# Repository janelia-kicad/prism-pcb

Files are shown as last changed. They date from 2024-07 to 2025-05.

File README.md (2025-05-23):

- [Repository Info](#org828f207)
- [Images](#orgb7f0c41)
- [Schematic](#org1bb097a)
- [PCB](#orgb5dbdc9)
- [Bill of Materials](#orgcb18792)
- [Development](#org51ea665)

    <!-- This file is generated automatically from metadata -->
    <!-- File edits may be overwritten! -->

# Repository Info

-   Project Name: prism-pcb
-   Synopsis: PCB for each prism in the Voigts Lab honeycomb maze.
-   Documentation Version: 2.1.0
-   Pcb Version: 2.1
-   Enclosure Version: 1.0
-   Supplemental BOM Version: 2.1.0
-   Release Date: 2025-05-23
-   Creation Date: 2024-06-27
-   Kicad Version: 9.0
-   License: BSD-3-Clause
-   URL: <https://github.com/janelia-kicad/prism-pcb>
-   Author: Peter Polidoro
-   Email: peter@polidoro.io
-   Copyright: 2025 Howard Hughes Medical Institute
-   References:
    -   [cluster-pcb](https://github.com/janelia-kicad/cluster-pcb)
    -   [TMC5130](https://www.analog.com/en/products/tmc5130.html)

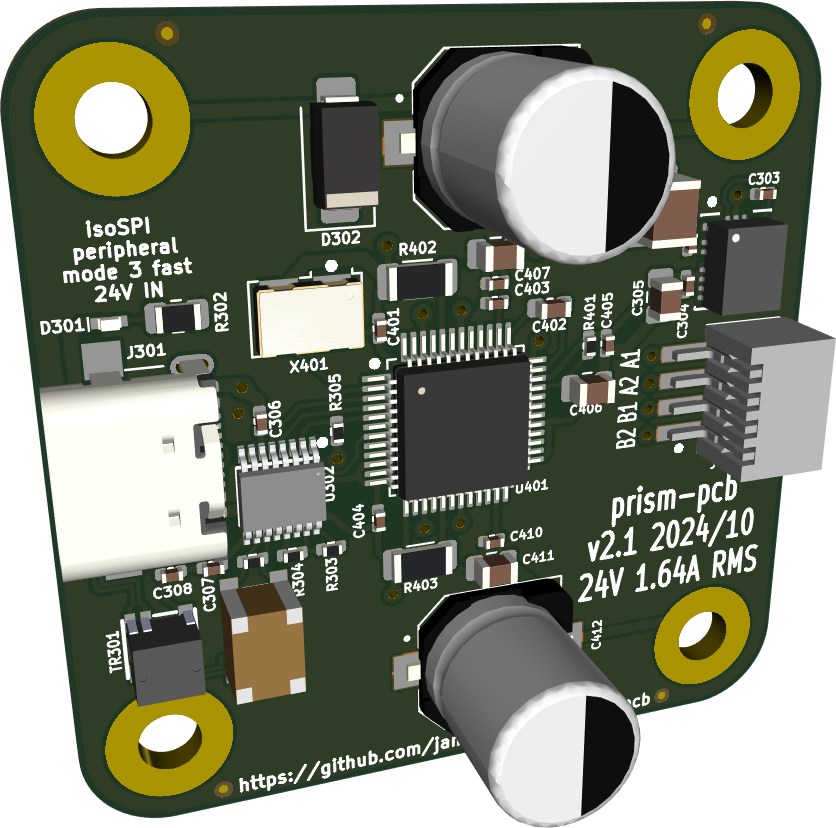
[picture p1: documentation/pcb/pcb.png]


# Images

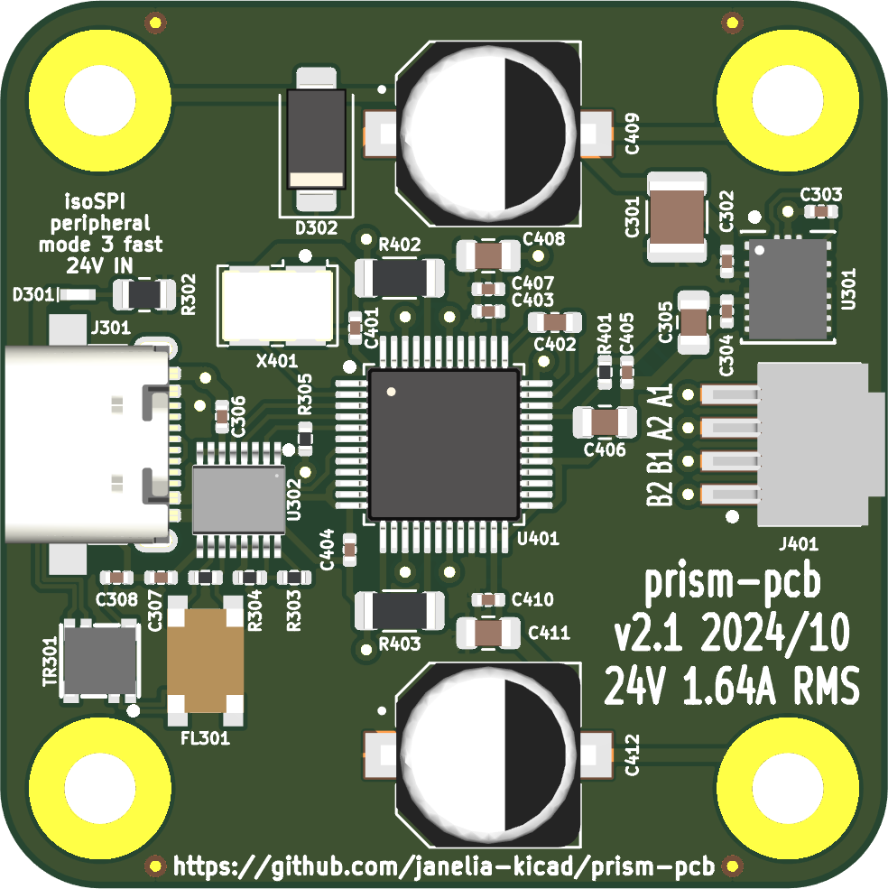
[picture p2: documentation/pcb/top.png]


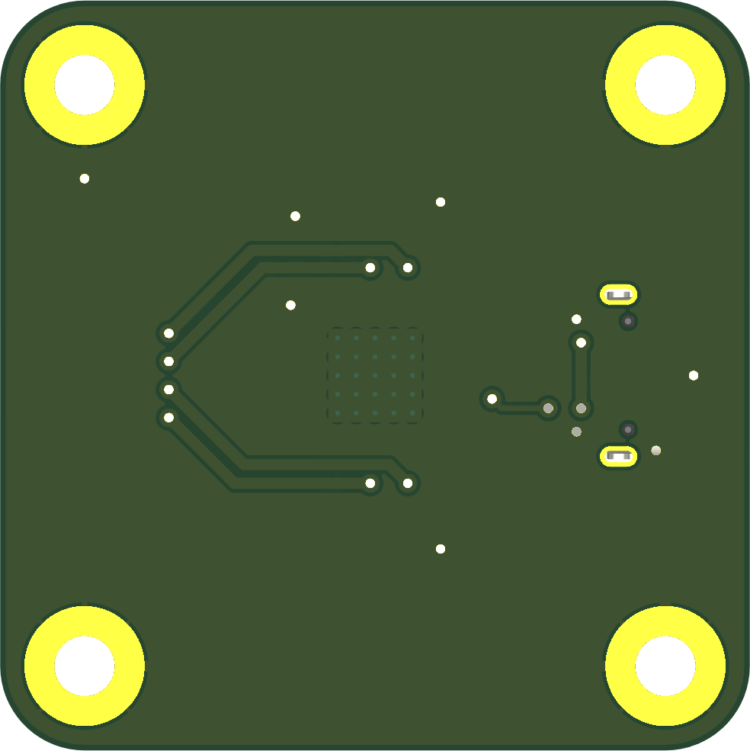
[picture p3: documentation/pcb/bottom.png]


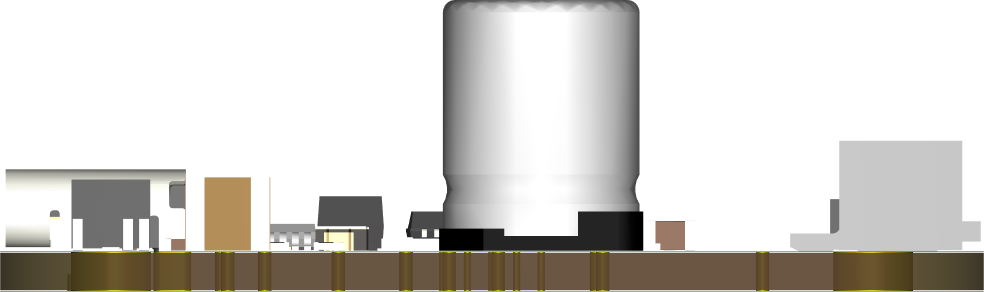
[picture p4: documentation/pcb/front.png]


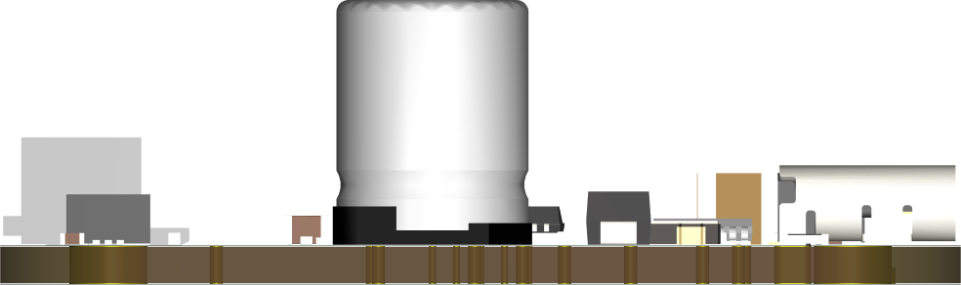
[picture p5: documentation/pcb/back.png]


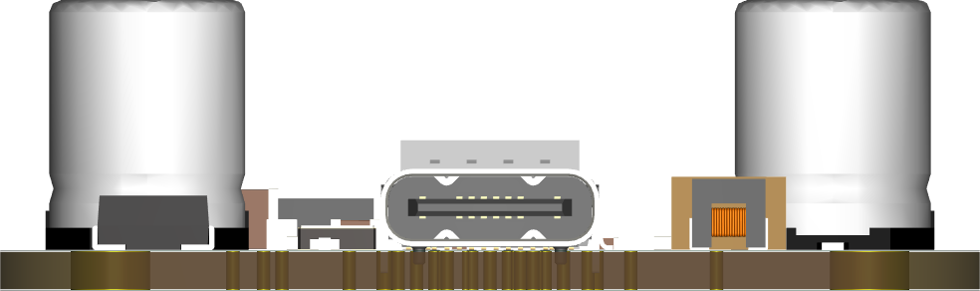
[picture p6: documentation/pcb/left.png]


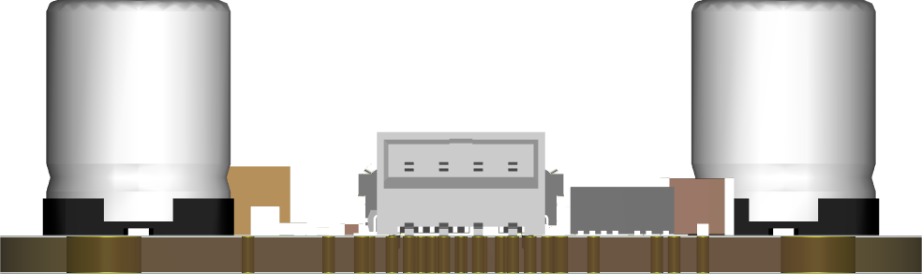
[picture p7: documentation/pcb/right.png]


# Schematic

[./documentation/schematic/prism-pcb.pdf](./documentation/schematic/prism-pcb.pdf)









# PCB











# Bill of Materials

## Board

| Item | Synopsis | Manufacturer Part Number | Manufacturer | Quantity | Reference(s) | Package |
|---- |--- |--- |--- |--- |--- |--- |
| 1 | 50V 3.3uF | FS32X335K500EGG | PSA(Prosperity Dielectrics) | 1 | C301 | 1210 |
| 2 | CAP CER 0.1UF 100V X5R | GRM155R62A104KE14D | Murata Electronics | 8 | C302 C306 C307 C401 C403 C404 C407 C410 | 0402 |
| 3 | CAP CER 1UF 25V X5R | GRT155R61E105KE01D | Murata Electronics | 2 | C303 C304 | 0402 |
| 4 | CAP CER 47UF 10V X5R | CGA0805X5R476M100MT | HRE | 2 | C305 C406 | 0805 |
| 5 | CAP CER 27pF 50V 5% | 0402CG270J500NT | FH (Guangdong Fenghua Advanced Tech) | 1 | C308 | 0402 |
| 6 | CAP CER 0.022UF 100V X7R | GCM188R72A223KA37D | Murata Electronics | 1 | C402 | 0603 |
| 7 | CAP CER 0.47UF 35V X5R | GRT155R6YA474KE01D | Murata Electronics | 1 | C405 | 0402 |
| 8 | CAP CER 2.2UF 100V X7T 0805 | GRM21BD72A225KE01L | Murata Electronics | 2 | C408 C411 | 0805 |
| 9 | CAP ALUM 100UF 20% 50V SMD | EEEHAH101UAP | Panasonic Electronic Components | 2 | C409 C412 | SMD D8xL10.2mm |
| 10 | LED RED CLEAR CHIP SMD | APHHS1005SURCK | Kingbright | 1 | D301 | 0402 |
| 11 | DIODE GEN PURP 200V 2A | ES2D | GOODWORK | 1 | D302 | SMA(DO-214AC) |
| 12 | CMC 22UH 200MA 2LN 1.2KOHM SMD | ACT45B-220-2P-TL003 | TDK | 1 | FL301 | 1812 |
| 13 | USB Type-C 2.0 16P 5A | GT-USB-7047C | G-Switch | 1 | J301 | SMD |
| 14 | CONN HEADER SMD R/A 4POS 1.5MM | 0874380443 | Molex | 1 | J401 | SMD |
| 15 | RES SMD 100 OHM 1% 62.5mW | 0402WGF1000TCE | UNI-ROYAL(Uniroyal Elec) | 1 | R301 | 0402 |
| 16 | RA73F 2A 2K32 0.1% 5K RL | RA73F2A2K32BTD | TE Connectivity Passive Product | 1 | R302 | 0805 |
| 17 | RES SMD 1.4K OHM 1% 62.5mW | RC0402FR-071K4L | YAGEO | 1 | R303 | 0402 |
| 18 | RES SMD 604 OHM 1% 100mW | ERJ2RKF6040X | PANASONIC | 1 | R304 | 0402 |
| 19 | RES SMD 1.8K OHM 5% 100mW | ERJ2GEJ182X | PANASONIC | 1 | R305 | 0402 |
| 20 | RES SMD 10 OHM 1% 62.5mW | RC0402FR-0710RL | YAGEO | 1 | R401 | 0402 |
| 21 | 0.12 750mW Current Sense Resistor | KRL1632E-M-R120-F-T5 | SUSUMU | 2 | R402 R403 | 1206 |
| 22 | Pulse Transformer 120uH 1CT:1CT | FB020G00 | Dongguan Mentech Optical & Magnetic  | 1 | TR301 | SMD-6P 3.5x3.2mm |
| 23 | DC-DC 5V 600mA Output 3-65V Input | TPSM365R6V5RDNR | Texas Instruments | 1 | U301 | QFN-11(3.5x4.5)  |
| 24 | SPI Isolator | LTC6820HMS#3ZZTRPBF | Analog Devices | 1 | U302 | MSOP-16 |
| 25 | IC MTR DRV BIPOLAR 5.5-46V | TMC5130A-TA | Analog Devices Inc./Maxim Integrated | 1 | U401 | TQFP-48-EP(7x7)  |
| 26 | XTAL OSC XO 16MHZ 5V SMD | S5D16.000000A20F30T | Shenzhen SCTF Elec | 1 | X401 | SMD5032-4P |

## Supplemental

| Item | Synopsis | Manufacturer Part Number | Manufacturer | Quantity | Cost  | Total |
|---- |--- |--- |--- |--- |----- |----- |
| 1 | USB 2.0 C Male to C Male 150mm | DH-20UE0062-NH | Cvilux USA | 1 | 4.75  | 4.75  |
| 2 | USB 2.0 C Male to C Male 1m | DH-20UE0063-NH | Cvilux USA | 1 | 5.74  | 5.74  |
| 3 | M3 Hex Standoff Male Female 10x5mm | 971100354 | Würth Elektronik | 4 | 0.63  | 2.52  |
| 4 | M3 Machine Screw 6mm | RM3X6MM 2701 | APM Hexseal | 4 | 0.58  | 2.32  |
| 5 | Supplemental BOM Version: 2.1.0 | | | | Total | 15.33 |

# Development

## Install Guix

[Install Guix](https://guix.gnu.org/manual/en/html_node/Binary-Installation.html)

## Generate Output from KiCad

### Remove previous versions

```sh
rm -rf ./documentation/3dmodels/* && rm -rf ./documentation/bom/* && rm -rf ./documentation/fabrication/* && rm -rf ./documentation/pcb/* && rm -rf ./documentation/schematic/*pcb
```

### Images

1.  3D Viewer

    Output directory: ../documentation/pcb
    
    -   pcb.png
    -   top.png
    -   bottom.png
    -   front.png
    -   back.png
    -   left.png
    -   right.png

2.  Trim

        make trimmed-images

3.  Schematic PDF

    File -> Plot
    
    Output directory: ../documentation/schematic
    
    Plot All Pages
    
    -   Output format PDF
    -   Page Size = Schematic size
    -   Plot drawing sheet
    -   Output mode = Color
    -   Color theme = KiCad Default
    -   Default line width = 0.006 in

4.  Schematic SVG

    File -> Plot
    
    Output directory: ../documentation/schematic
    
    Plot All Pages
    
    -   Output format SVG
    -   Page Size = Schematic size
    -   Plot drawing sheet
    -   Output mode = Color
    -   Color theme = Solarized Light
    -   Default line width = 0.012 in

5.  PCB SVG

    Add Edge.Cuts, holes, and dimensions to User.Drawings
    
    File -> Plot
    
    Output directory: ../documentation/pcb
    
    -   Plot format SVG
    -   Include Layers
        -   User.Drawings
        -   F.Silkscreen
        -   B.Silkscreen
        -   F.Fab
        -   B.Fab
    -   Plot on All Layers
        -   Edge.Cuts
    -   Plot footprint values
    -   Plot reference designators
    -   SVG Options
        -   Precision = 4
        -   Output mode = color
    
        make cropped-svg

### Fabrication Files

1.  Gerbers

    File -> Fabrication Outputs -> Gerbers (.gbr)
    
    Output directory: ../documentation/fabrication/gerbers
    
    Include Layers:
    
    -   F.Cu
    -   F.Paste
    -   F.Silks
    -   F.Mask
    -   F.Fab
    -   B.Cu
    -   B.Paste
    -   B.Silks
    -   B.Mask
    -   B.Fab
    -   Edge.Cuts - (contain the board outline/cutouts.)
    -   In1.Cu, In2.Cu … - (needed for 4/6 layer designs.)
    
    Options:
    
    -   Select Plot reference designators, otherwise designators will not appear on silkscreen layers.
    -   Select Check zone fills before plotting
    -   Select Use Protel filename extensions, this is recommended as JLCPCB prefers Protel filename extensions.
    -   Select Subtract soldermask from silkscreen, this ensures no silkscreen on pads.
    -   Coordinate format 4.6 unit mm

2.  Drill and Map Files

    Output directory: ../documentation/fabrication/gerbers
    
    Options:
    
    -   Excellon drill file format
    -   Check Use alternate drill mode for "Oval Holes Drill Mode".
    -   Check Absolute for "Drill Origin".
    -   Check Millimeters for "Drill Units".
    -   Check Decimal format for "Zeros Format".
    -   Gerber X2 map file format
    
    Zip gerber files
    
        zip ./documentation/fabrication/gerbers.zip ./documentation/fabrication/gerbers/*

3.  BOM

    Generate BOM from schematic editor using blank command line to create bom xml file.

4.  POS

    File -> Fabrication Outputs -> Component Placement (.pos)
    
    Output directory: ../documentation/fabrication/
    
    Settings:
    
    -   Format = CSV
    -   Units = Millimeters
    -   Files = Single file for board
    -   Do not use drill/place file origin
    
    Modify pos files:
    
    -   Ref -> Designator
    -   PosX -> Mid X
    -   PosY -> Mid Y
    -   Rot -> Rotation
    -   Side -> Layer

5.  Step

    File -> Export -> Step
    
    Output directory: ../documentation/3dmodels/pcb.step
    
    -   Drill/place file origin
    -   Overwrite old file
    -   Standard Board outline chaining tolerance

## Edit metadata.org

    make metadata-edits

## Tangle metadata.org

    make metadata

## Edit project

    make kicad-edits
    exit

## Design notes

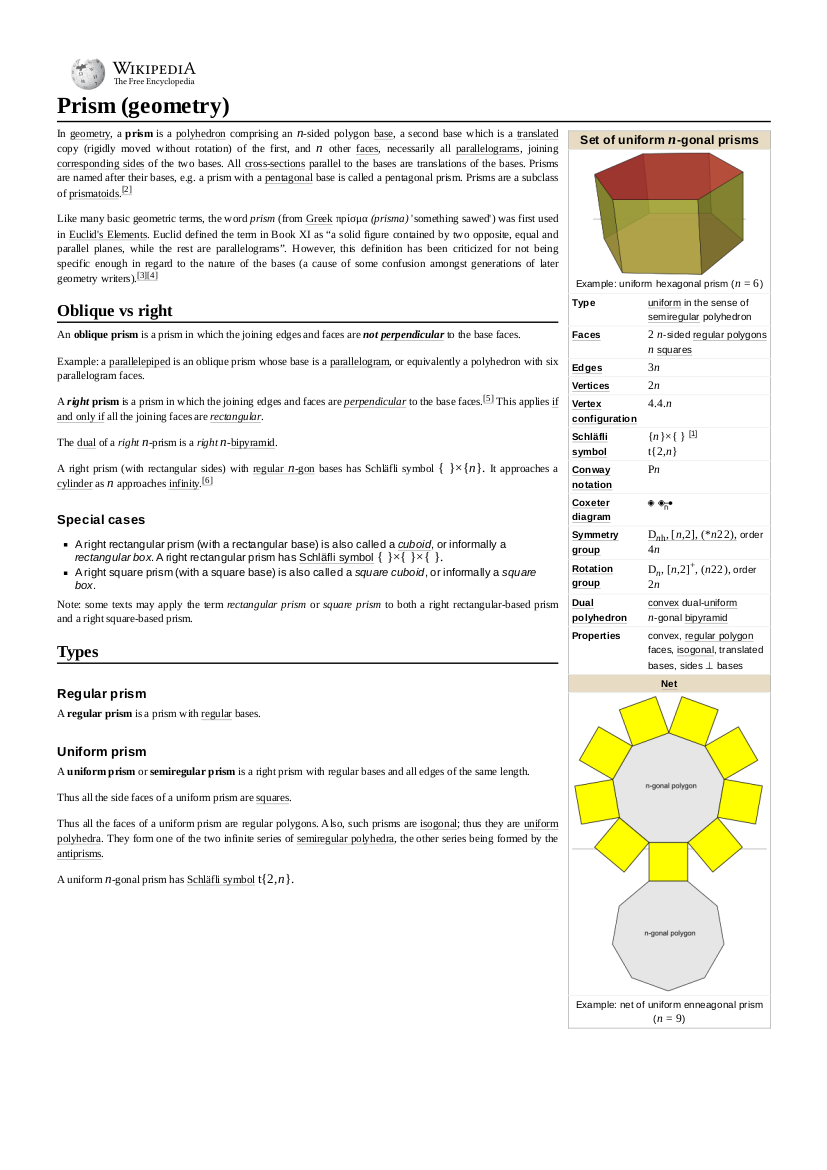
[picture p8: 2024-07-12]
documentation/images/prism.png

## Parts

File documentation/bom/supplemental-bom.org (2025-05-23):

#+OPTIONS: toc:nil title:nil num:nil ^:nil
#+LATEX_HEADER: \usepackage{adjustbox}
#+LATEX_HEADER: \usepackage[margin=2cm]{geometry}
* Supplemental BOM
- Project Name: prism-pcb
- Synopsis: PCB for each prism in the Voigts Lab honeycomb maze.
- Release Date: 2025-05-23
- URL: https://github.com/janelia-kicad/prism-pcb
- Author: Peter Polidoro
- Email: peter@polidoro.io
#+BEGIN_TABLE
#+LATEX: \adjustbox{max width=\linewidth}{
#+ATTR_LATEX: :center nil
| Item | Synopsis                                               | Manufacturer Part Number | Manufacturer     | Quantity |  Cost | Total |
|------+--------------------------------------------------------+--------------------------+------------------+----------+-------+-------|
|    1 | USB 2.0 C Male to C Male 150mm                         | DH-20UE0062-NH           | Cvilux USA       |        1 |  4.75 |  4.75 |
|    2 | USB 2.0 C Male to C Male 1m                            | DH-20UE0063-NH           | Cvilux USA       |        1 |  5.74 |  5.74 |
|    3 | M3 Hex Standoff Male Female 10x5mm                     | 971100354                | Würth Elektronik |        4 |  0.63 |  2.52 |
|    4 | M3 Machine Screw 6mm                                   | RM3X6MM 2701             | APM Hexseal      |        4 |  0.58 |  2.32 |
|------+--------------------------------------------------------+--------------------------+------------------+----------+-------+-------|
|    5 | Supplemental BOM Version: 2.1.0 |                          |                  |          | Total | 15.33 |
#+TBLFM: $1=@#-1::$7=$5*$6;%0.2f::@>$7=vsum(@2..@-1);%0.2f
#+LATEX: }
#+END_TABLE

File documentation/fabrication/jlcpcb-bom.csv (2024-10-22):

Comment | Designator | Footprint | LCSC
50V 3.3uF | C301 | 1210 | C1021610
CAP CER 0.1UF 100V X5R | C302 C306 C307 C401 C403 C404 C407 C410 | 0402 | C162178
CAP CER 1UF 25V X5R | C303 C304 | 0402 | C711085
CAP CER 47UF 10V X5R | C305 C406 | 0805 | C6119904
CAP CER 27pF 50V 5% | C308 | 0402 | C1557
CAP CER 0.022UF 100V X7R | C402 | 0603 | C161234
CAP CER 0.47UF 35V X5R | C405 | 0402 | C711580
CAP CER 2.2UF 100V X7T 0805 | C408 C411 | 0805 | C2981733
CAP ALUM 100UF 20% 50V SMD | C409 C412 | SMD D8xL10.2mm | C336425
LED RED CLEAR CHIP SMD | D301 | 0402 | C2852592
DIODE GEN PURP 200V 2A | D302 | SMA(DO-214AC) | C2922175
CMC 22UH 200MA 2LN 1.2KOHM SMD | FL301 | 1812 | C88055
USB Type-C 2.0 16P 5A | J301 | SMD | C963218
CONN HEADER SMD R/A 4POS 1.5MM | J401 | SMD | C564208
RES SMD 100 OHM 1% 62.5mW | R301 | 0402 | C25076
RA73F 2A 2K32 0.1% 5K RL | R302 | 0805 | C3961061
RES SMD 1.4K OHM 1% 62.5mW | R303 | 0402 | C375491
RES SMD 604 OHM 1% 100mW | R304 | 0402 | C2076855
RES SMD 1.8K OHM 5% 100mW | R305 | 0402 | C409855
RES SMD 10 OHM 1% 62.5mW | R401 | 0402 | C138066
0.12 750mW Current Sense Resistor | R402 R403 | 1206 | C2076122
Pulse Transformer 120uH 1CT:1CT | TR301 | SMD-6P 3.5x3.2mm | C19673866
DC-DC 5V 600mA Output 3-65V Input | U301 | QFN-11(3.5x4.5) | C19078014
SPI Isolator | U302 | MSOP-16 | C514444
IC MTR DRV BIPOLAR 5.5-46V | U401 | TQFP-48-EP(7x7) | C188832
XTAL OSC XO 16MHZ 5V SMD | X401 | SMD5032-4P | C387234

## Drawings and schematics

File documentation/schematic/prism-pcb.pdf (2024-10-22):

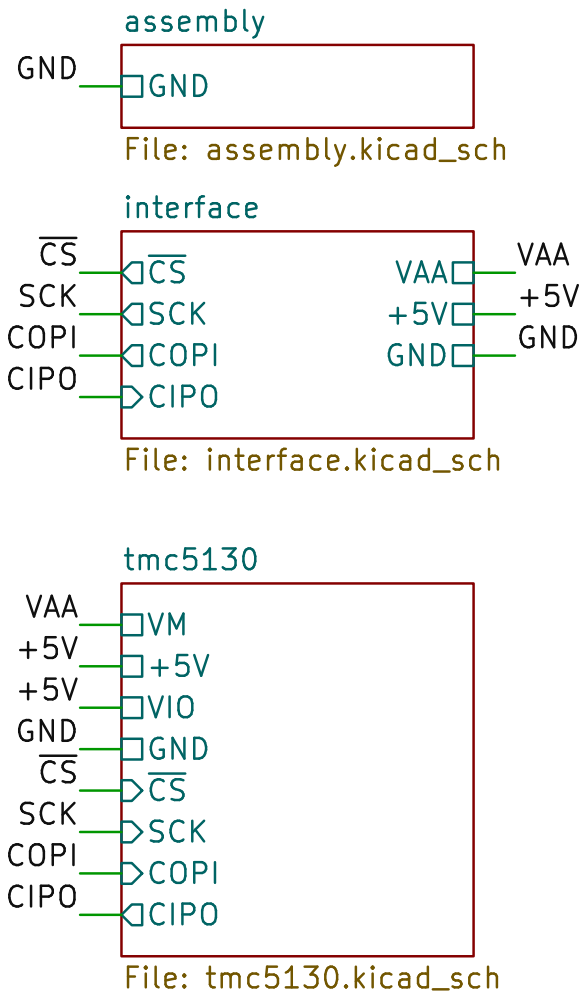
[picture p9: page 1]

interface File: interface.kicad_sch GND

SCK COPI ~{CS} CIPO

Id: 1/4 Title: prism-pcb

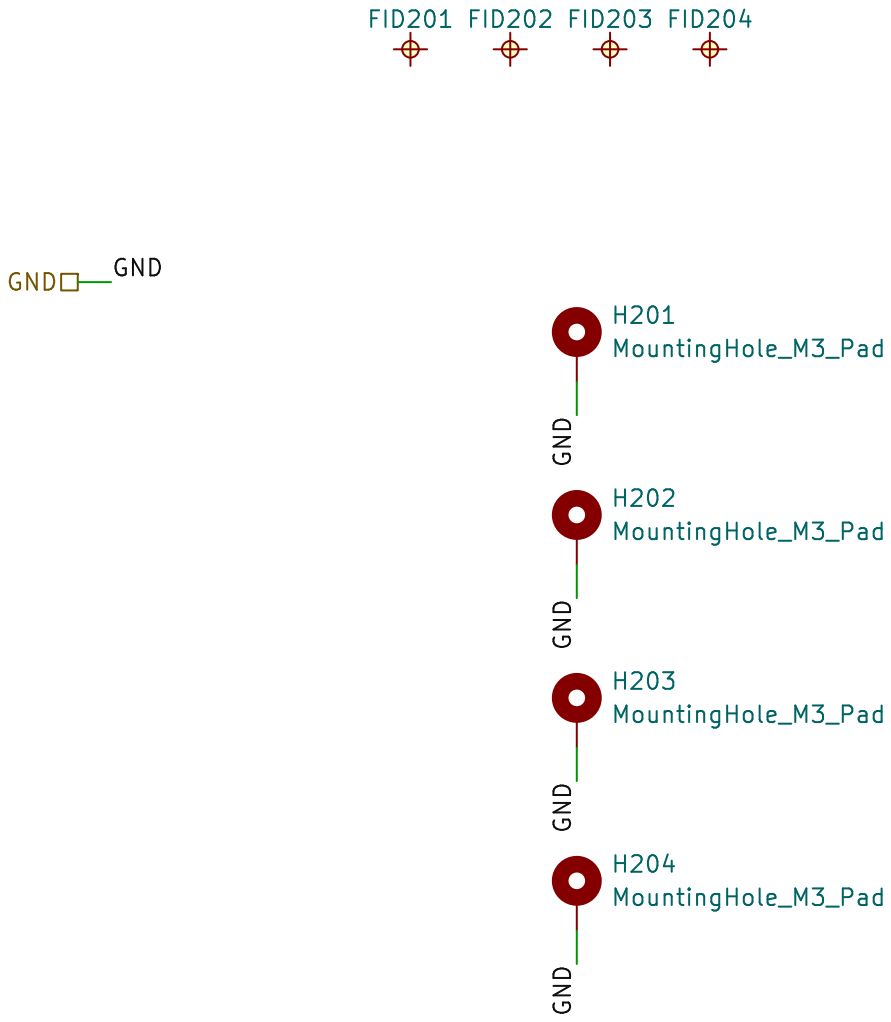
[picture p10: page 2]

Id: 2/4 Title: prism-pcb

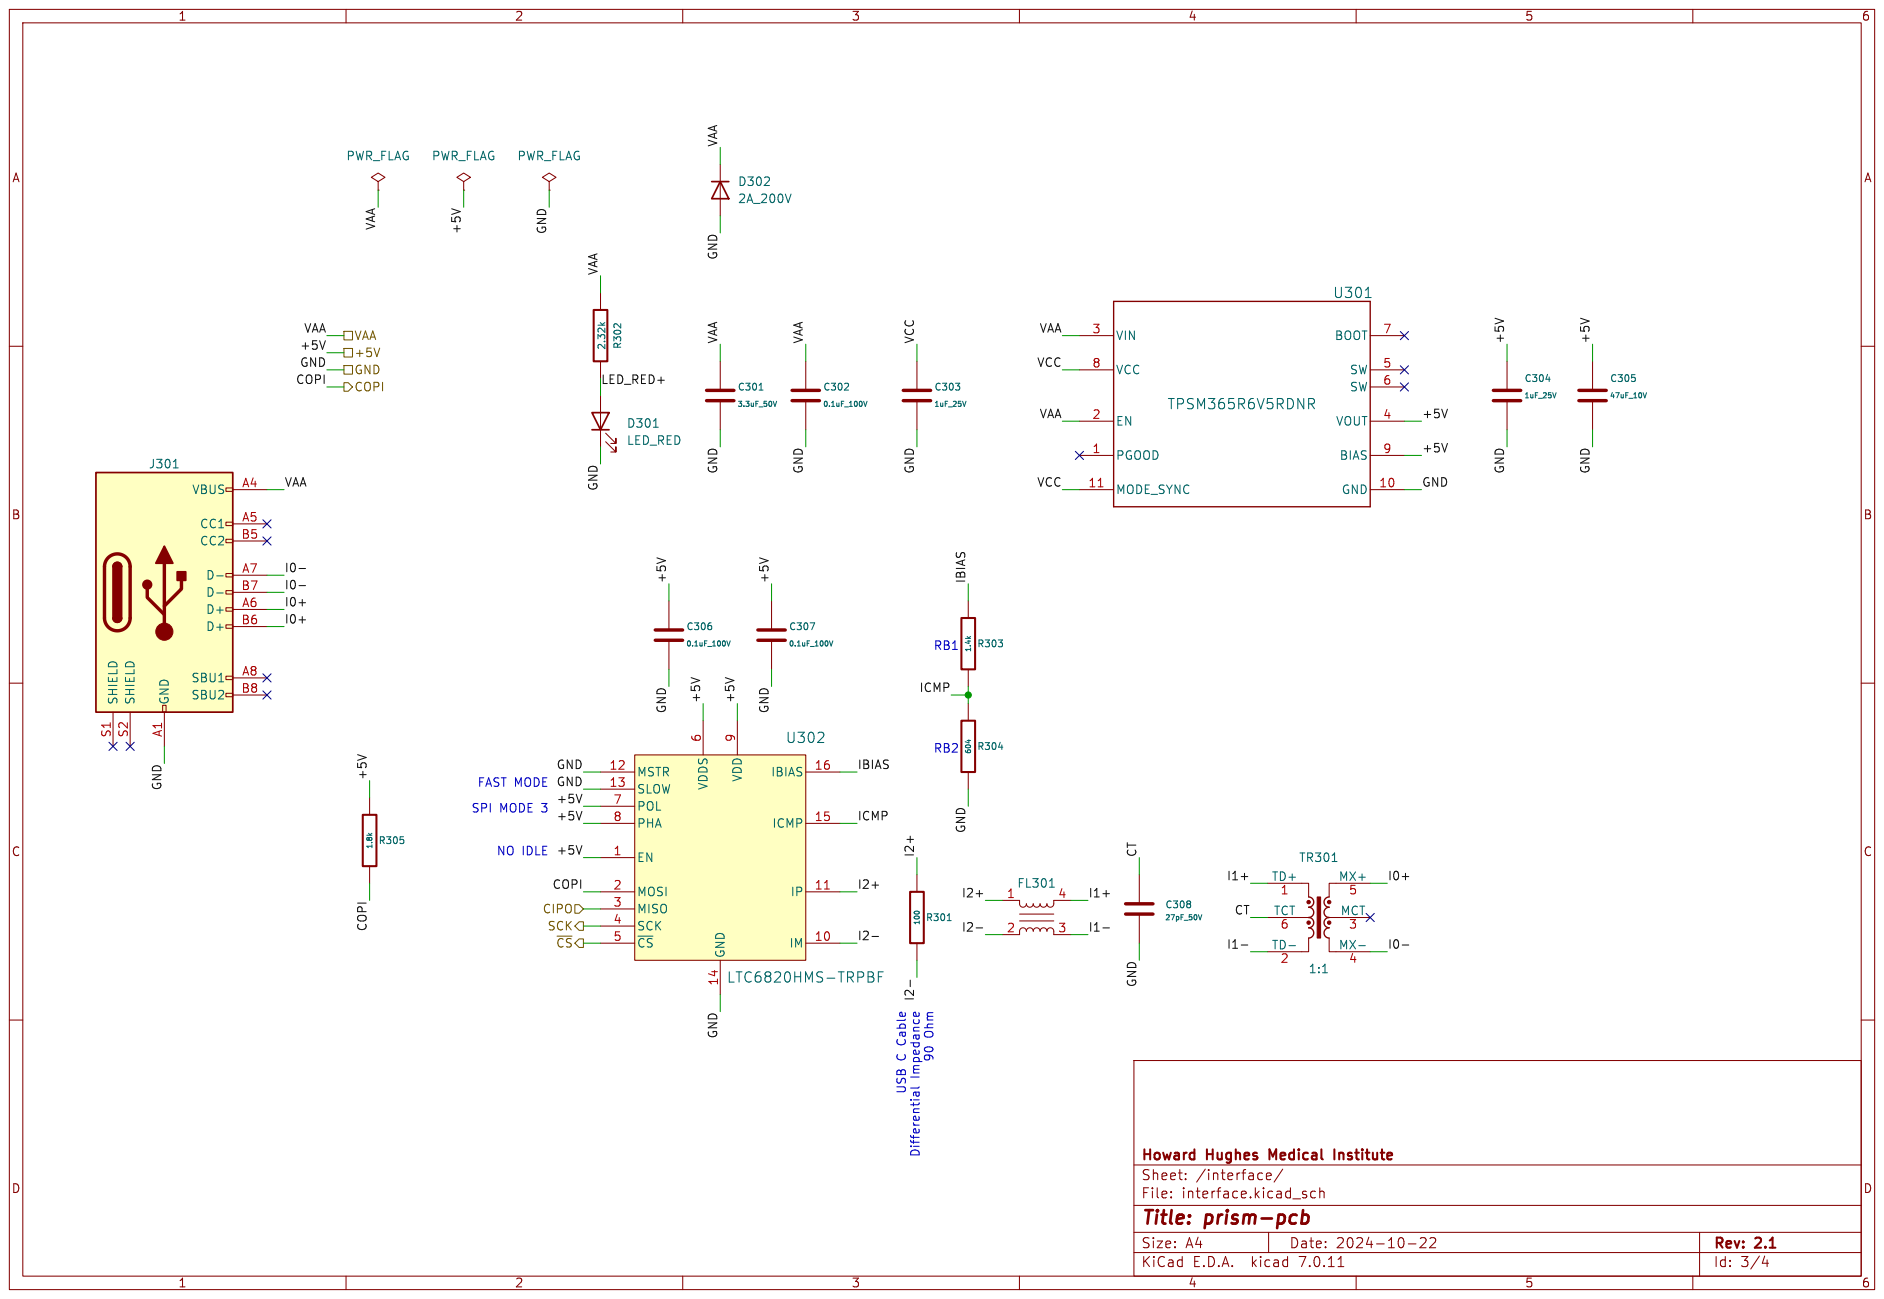
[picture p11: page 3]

Id: 3/4 Title: prism-pcb

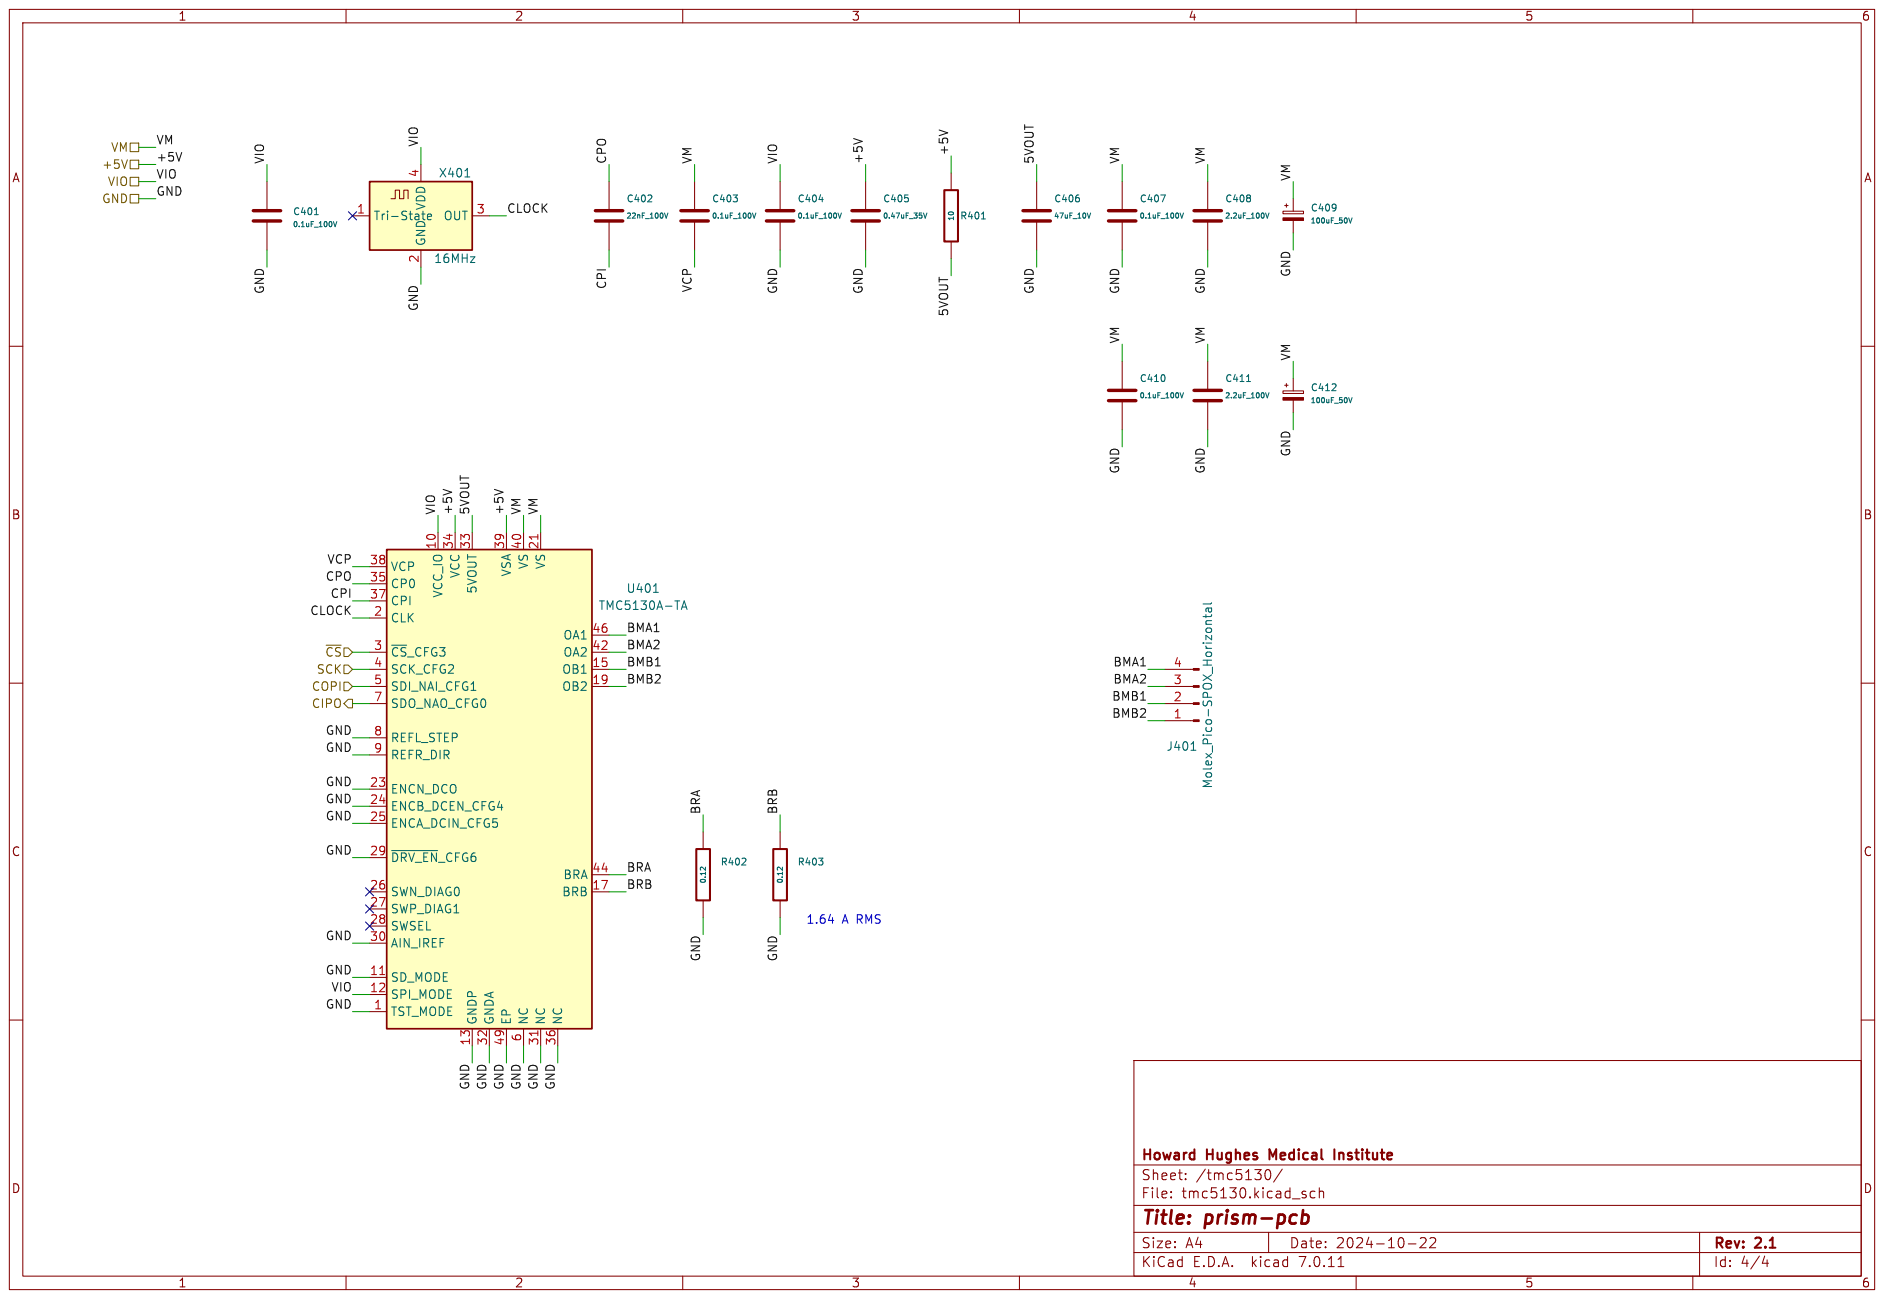
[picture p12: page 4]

Id: 4/4 Title: prism-pcb

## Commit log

2024-06-27 TMC5160 -> TMC5130 component
    [interface.kicad_sch, tmc5130.kicad_sch]
2024-06-28 Add some components
    [interface.kicad_sch]
2024-07-01 Add components
    [interface.kicad_sch]
2024-07-02 Add components from jlcpcb
    [assembly.kicad_sch, interface.kicad_sch, tmc5130-uart.kicad_pcb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]
2024-07-02 Connect DC/DC
    [interface.kicad_sch]
2024-07-09 Switch capacitor
    [interface.kicad_sch]
2024-07-10 Change capacitor
    [interface.kicad_sch]
2024-07-12 tmc5130-uart -> prism-pcb
    [assembly.kicad_sch, interface.kicad_sch, prism-pcb.kicad_pcb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]
2024-07-12 Update power supply connections
    [interface.kicad_sch, prism-pcb.kicad_sch, tmc5130.kicad_sch]
2024-07-12 Initial footprint layout
    [interface.kicad_sch, prism-pcb.kicad_pcb, tmc5130.kicad_sch]
2024-07-13 Rearrange footprints
    [prism-pcb.kicad_pcb]
2024-07-13 Place all footprints
    [interface.kicad_sch, prism-pcb.kicad_pcb, prism-pcb.kicad_sch]
2024-07-13 Fix initial drc errors
    [assembly.kicad_sch, interface.kicad_sch, prism-pcb.kicad_pcb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]
2024-07-13 Rearrange text
    [prism-pcb.kicad_pcb]
2024-07-14 Finish pcb layout
    [assembly.kicad_sch, interface.kicad_sch, prism-pcb.kicad_pcb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]
2024-07-14 Update metadata
    [interface.kicad_sch, jlcpcb-bom.csv]
2024-07-15 Add fabrication files
    [jlcpcb-prism-pcb-bottom-pos.csv, jlcpcb-prism-pcb-top-pos.csv, prism-pcb-B_Cu.gbl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]
2024-07-15 Updated fabrication files
    [jlcpcb-prism-pcb-all-pos.csv, jlcpcb-prism-pcb-bottom-pos.csv]
2024-07-15 Update svg files
    [prism-pcb.kicad_pcb]
2024-07-15 Add footprint values to F.Fab
    [prism-pcb.kicad_pcb]
2024-07-16 Add cluster-pcb to metadata
2024-07-25 Update capacitor package
    [jlcpcb-bom.csv, tmc5130.kicad_sch]
2024-07-25 Updated capactitors for v1.1
    [assembly.kicad_sch, interface.kicad_sch, jlcpcb-bom.csv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]
2024-08-07 Update schematic to use external 5V supply
    [assembly.kicad_sch, interface.kicad_sch, prism-pcb.kicad_sch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]
2024-08-22 Change to 5V xtal, add capacitors and led, use TMC5130 5V external
    [assembly.kicad_sch, interface.kicad_sch, prism-pcb.kicad_pcb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]
2024-08-22 Update documentation
    [jlcpcb-bom.csv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]
2024-08-22 Updated csv files
    [jlcpcb-bom.csv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]
2024-09-09 Change connector and add diode
    [assembly.kicad_sch, interface.kicad_sch, prism-pcb.kicad_pcb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]
2024-09-10 Changed connector, added uart pullup, grounded more pins
    [assembly.kicad_sch, interface.kicad_sch, jlcpcb-bom.csv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]
2024-09-16 Update supplemental bom
2024-09-17 Added LTC6820
    [interface.kicad_sch, prism-pcb.kicad_sch, tmc5130.kicad_sch]
2024-09-18 Add transformer and choke
    [assembly.kicad_sch, interface.kicad_sch, prism-pcb.kicad_pcb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]
2024-09-20 Finish v2.0 layout
    [assembly.kicad_sch, interface.kicad_sch, prism-pcb.kicad_pcb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]
2024-09-23 Switch to USB connector
    [assembly.kicad_sch, interface.kicad_sch, prism-pcb.kicad_pcb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]
2024-09-26 Preliminary routing for v2.0
    [assembly.kicad_sch, interface.kicad_sch, prism-pcb.kicad_pcb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]
2024-09-26 Fix USB slot size
    [prism-pcb.kicad_pcb]
2024-10-21 Fix pullup resistor value
    [assembly.kicad_sch, interface.kicad_sch, prism-pcb.kicad_pcb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]
2024-10-22 Finish v2.1
    [assembly.kicad_sch, interface.kicad_sch, jlcpcb-bom.csv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]
2025-05-23 Update kicad to version 9
    [assembly.kicad_sch, interface.kicad_sch, prism-pcb.kicad_pcb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]
2026-06-09 Update guix files for kicad 10
